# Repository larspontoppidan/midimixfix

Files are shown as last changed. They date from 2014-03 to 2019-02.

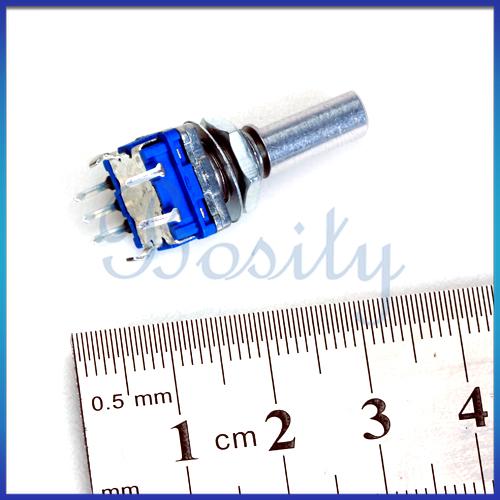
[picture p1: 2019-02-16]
HW/Components/Rotary encoder/14002056_5_image_81994.jpg

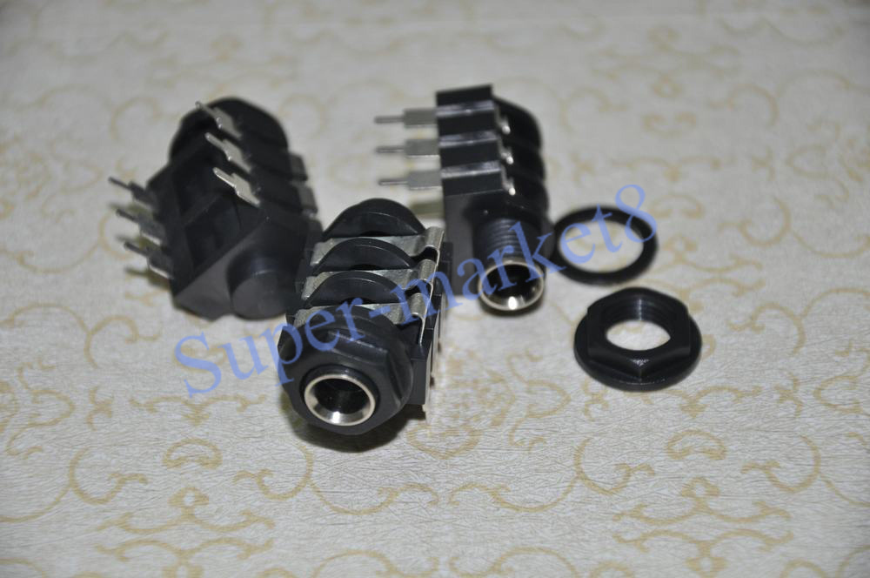
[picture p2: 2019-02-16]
HW/Components/JACK receptacle/B2.JPG

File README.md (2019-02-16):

# MidiMixFix

*Now open source!*

Midimixfix is a standalone MIDI processing unit with custom designed electronics and software for mixing and processing streams of MIDI.

## Features at a glance

- Two MIDI inputs and one MIDI output.
- Two pedal inputs assignable to MIDI controllers.
- All inputs can have their MIDI channels filtered, reassigned, merged or individually processed very flexibly. MIDI messages can be modified and generated.
- Midimixfix is independent of a PC. Configuration is done using the buttons and display.
- Transformation of continuous MIDI message values based on configurable curves.
- Splitting of polyphony into seperate monophonic MIDI channels for control of individual notes.
- Aftertouch processing, smoothing and reassignment to other controllers.
- Conditional processing based on triggers or keyboard split.
- Analysis of MIDI data with the MIDI logger feature.
- Save/Load of configuration presets. One preset is loaded at start up.
- Software in Midimixfix can be upgraded using the USB connection.



Back of midimixfix

## Links

Read more here: https://larsee.com/blog/tag/midimixfix.html

Youtube video demonstrations:
- [Midimixfix demonstration, fixing key velocity using curve filter](https://www.youtube.com/watch?v=JRt7MXFQuEk)
- [Vibrato Pedal on a Piano? Enhancing Rachmaninoff with Midimixfix](https://www.youtube.com/watch?v=KIDRwiXo5tw)
- [Polyphonic aftertouch effects with Midimixfix channel split feature](https://www.youtube.com/watch?v=yqUHe00-khM)

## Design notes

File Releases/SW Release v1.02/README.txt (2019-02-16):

Programming MidiMixFix in Windows:
-----------------------------------

Three things are needed to flash upgrade the software in MidiMixFix with the contents of this zip file:

1. USBasp driver installed

2. Avrdude installed (available in WinAVR package)

3. Midimixfix in bootloader mode connected with USB cable

Then, the batch file "Flash Midimixfix(...).bat" should run successfully. 

Detailed instructions:
----------------------

1. Installing USBasp driver:

- Go to http://www.fischl.de/usbasp/  and download for driver for windows, for example: http://www.fischl.de/usbasp/usbasp-windriver.2011-05-28.zip

- Unpack zip file.

- While holding select button, connect MidiMixFix to PC with USB cable, in order to activate the USBasp device. Now Windows will discover a new USB device and may fail to install a driver for it. It this happens, go to control panel and find the non-working USB device, in properties change the driver to the one from the zip file.

2. Installing WinAVR:

- Go to http://sourceforge.net/projects/winavr/files/ and download the latest version of WinAVR. Install it.

3. A sure way to bring Midimixfix in bootloader mode is to hold down the Select button while connecting the USB cable. This will make Midimixfix start up in bootloader mode. The LCD may show two black bars in this mode.

Now execute "Flash MidiMixFix(...).bat"!

By Lars Ole Pontoppidan, 2014-01-19

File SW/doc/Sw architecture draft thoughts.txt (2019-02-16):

 12345678901234567890
----------------------
-                    -
-                    -
-                    -
-                    -
----------------------

----------------------
-In Flt Flt Flt Flt O-
- 1                 1-
- 2                 2-
-                    -
----------------------

Functions

In1
In2

All to chan 1
OY1

VelocityTransform1
VelocityTransform2
VelocityTransform3
VelocityTransform4
Arpeggiate
Poly To Channels
 Aftertouch
AfterTouch To Volume
Att Vel To Volume
Rel Vel To Volume

Kindof a simpler approach:

Use cases:
- Poly fan out

----------------------
- Preset  : 1        -
- V.Curve : Neutral  -
- Pedal   : Eff OnOff-
- Patch   : 3,127,128-
- Eff.mod : Poly2Chan-
- Eff.ctl : Volume   -
- Save to preset 1   -
----------------------

Preset:  1..16

Filter:  AllPass, NoCrap, OnlyNotes, OnlyChn1, OnlyChn2

V.Curve: Neutral, HardStart, SoftStart, HardEnd, 

Pedal:   Eff OnOff
         Volume
         Pan
         MidiCtl ..
         
PatchChg: Off
          3,127,128
         
Eff.Mode: Off
          PolyChan     Poly aftertouch to channels
          EPolyChan    Emulated poly aftertouch to channels
          EPitchBnd    Emulated pitch bend

For PolyChan:
          
Eff.Ctl : Volume       Poly aftertouch controls volume
          Pan          Poly aftertouch controls pan
          MidiCtl ..   Poly aftert. controls midictrl something

For EPolyChan:
          
Eff.Ctl : Volume       Poly aftertouch controls volume
          Pan          Poly aftertouch controls pan
          MidiCtl ..   Poly aftert. controls midictrl something

----------------------
- V.Curve : Neutral  -
- Pedal   : Eff OnOff-
- Eff.mode: Poly2Chan-
- Eff.ctrl: Volume   -
----------------------

GPIO BUDGET
-----------

Function        IO   Special
MIDI IO         2    UART
Sec. MIDI IO    4    UART
Display data    8    Same port
Display ctl     3
Pedal 1/2       2    ADC
Indicator led   1    Evt. pwm
V-USP           3    1x Ex. int.
Rotary enc      2    2x Ex. int.
Push buttons    2    

Total          25

---------------

Architecture

hal module sets up midi IO uarts and sends interrupts for the uart activities

midimessage module parses incoming midi data:

hal:ISR
 ->  midimessage:Parser 
     -> midiio:MsgAllocate   (reserve mmsg)
     -> midiio:MsgHandOver   (indicate mmsg is complete)
        -> midilogger
        -> midiprocess
        -> start transmission   

What if the parser works like this

hal     midiparser           midiio
        w. statemachine      w. buffer
 
ISR ->  Parser         ->    msg_index = StartNewMsg(source, midi_status)
                             AddMsgData(msg_index, midi_data)
                             FinishMsg(msg_index, message_status)

So, the software architecture should be modular.

In general the modules can do the following:

1. Monitor messages
2. Filter messages 
3. Change messages
4. Generate new messages
5. Have configuration options, a presentation in the menu
6. Have an entire LCD screen mode (curve edit, midi logger)

Is it feasible and desireable to have a module interface that can accomplish all this?

The modules must be able to:

A. Hook new message ISR
B. Hook tick ISR
C. Hook main thread idle loop
D. Call message generation API

The A, B, C, D possibilities are rather straightforward and will enable modules to solve 1, 2, 3, 4.

What is not solved at this point is 5, 6. 

What is required for a presentation in the menu? How should the menu look like?

Boot screen:

----------------------
|** Midimixfix 0.1 **|
|>Preset: <no preset>|
| In1 setup: Through |   | In1 setup: Process | | In1 setup: Through |
|  Send realtime msg.|
| In2 setup: Process |
|  Stop realtime msg.|   |  Send realtime msg.|
| Show...            |   | Show > status view | quick help, input log, output log
| Pass filter: ON    |
|  In1 only Ch1      |
|  In2 only Notes    |
|  In2 only Ch2      |
|  In2 only Notes,AT.|
|  Manage...         |   |  Manage > Add      |   / Remove / Reset
| Stop filter: ON    |
|  Stop C.Variation  |
|  Stop ProgChg      |
|  Stop ATouch       |
|  Manage...         |   |  Manage... Add     |   / Remove / Reset
| Map channel: ON    |
|  Map In1 Ch3       |
|  To  Ch7           |
|  Map In2 Ch*       |
|  To  Ch6           |
|  Manage...         |   |  Manage... Add     |   / Remove / Reset
| Map controller: ON |
|  Map C.Modulation  |
|  To  C.Expression  |
| Pedal 1: ON        |
|  Calib. 000 127    |
|  To  C.Expression  |
| Pedal 2: ON        |
|  Calib. 000 127    |
|  To  Chan.A.Touch  |
| Curve: ON          |
|  On N.On vel.      |
|  0,32,64,96,127    |
|  On A.Touch        |
|  0,32,64,96,127    |
|  On C.Modulation   |
|  0,32,64,96,127    |  On select the curve window is displayed
|  Manage            |  |  Manage: Add / Remove |
----------------------

Okay, so what general structure is needed in the menu system:

A menu item can be:
 - Titlemenu   
 - SubMenu    (indented by one)
 
A menu entity contains:
 - One TitleMenu (may change text)  EntityItem 0
 - Zero or more SubMenu items       EntityItem 1, 2, 3...

Both TitleMenu and SubMenu can react to user input:
 - User select: Example: edit mode 0 -> 1 -> 2 -> 0
 - User turn: If edit mode is 0 menu will scroll on to next menu item
 - User turn: If edit mode > 0, menu will send turn events to EntityItem
   Now EntityItem may change it's representation and cursor position

Generally, Menu module will request MenuEntities for their representation
when necessary:

  uint8_t  SomeFilterGetSubMenus(void)
  void     SomeFilterGetMenuText(char *dest, uint8_t item)   
              // 0 is TitleMenu, 1, 2... SubMenus

When user does something to a menu item, Menu module will call:

  uint8_t SomeFilterMenuEvent(uint8_t item, uint8_t edit_mode, uint8_t user_event, int8_t knob_delta)

The user_event can be:  
  0:   Exit
  1:   Select
  2:   Knob turned (no push)
  3:   Knob turned (push)
 
The knob_delta is a signed 8-bit indicating how much the know was turned

The function must return:
  Value: 0     Edit mode not available
  Value: 1-18  Set cursor here
  Flag:  0x20  Update this line in menu
  Flag:  0x40  Update entire menu
  Flag:  0x80  I want to control the entire LCD
  
If 0x80 is returned, the menu module will stop doing anything to the display and just keep on sending the user events to the module. When the menu module receives an Exit event, it will be sent to the module, and then the menu will take over the display again.

------ Phew. That should solve the requirements 5, 6.

To summarize, modules that integrates in the Midimixfix platform must implement seven functions:

 void Initialize(void)
 
 void MessageIsrHook(mmsg_t *msg)
 void TickIsrHook(void)
 void MainLoopHook(void)
 
 uint8_t GetSubMenuCount(void)
 void    GetMenuText(char *dest, uint8_t item)
 uint8_t MenuEvent(uint8_t item, uint8_t edit_mode, uint8_t user_event, int8_t knob_delta)

... Now. How to implement this interface. It has to be handled by a ModuleFactory module.

------- What filters makes sense to have:

Both pass filters  / stop filters and mapping seems to solve
related tasks. Does it make sense to have indivitual pass / stop / map
filters? Or should they be combined into one multipurpose filter?

Two filters:

---- Block filter ----

Allows a number of rules with the following structure:

Input:   In1 In2 In*
Mode:    Only allow / Stop
Subject: Chan1 - Chan16, 
         Notes, Key AT, Ctl.chg, Prog.chg, Chan.AT. P.Wheel, System

"In* only Chan1    "
"In2 stop Chan3    "

"In1 only prog.chg."

---- Map filter: ----

Allows rerouting of channels and controllers.

The rules have the following structure:

Input:   In1 In2 In*
Map:     Chan1 - Chan16, P.Wheel, Chan.AT, Ctl:0 to Ctl:64
To:      Chan1 - Chan16, P.Wheel, Chan.AT, Ctl:0 to Ctl:64, or NULL

Map and Block (OFF)
"In1 Chan2"
  To block"
"In:1 Ctl:4"
  To Ctl:6"
"In:1 Chan:1"
  To Chan:2

---- Curve filter: ----
   
Allows shaping 7-bit values according to curve settings

The curve rules have the following structure:

Input:    In1 In2 In*
Param.:   Note-On All, Note-On White, Note-On Black, Note-Off
          Key AT, Chan AT, 
Shape:    Low point, Curve type, High point

Neutral:              0   1  127
To lift up minimum:   30  1  127
To advance minimum:   -30 1  127

To use a non-linear curve:  0   0.8  127  (resembling gamma 0.8)
To use a non-linear curve:  0   1.3  127
To use a non-linear curve:  0   S    127  (having a more steep center)
To use a non-linear curve:  0   N    127  (having a more flat center)

The available non-linear curves could be:

"0.5", "0.8", "1.3", "2  ", "S", "N"

The filter algorithm to be used live would be like:

1. Look up value in non-linear curve table, or use directly
2. Multiply gain  (fixed point)
3. Add offset
4. Bounded conversion to non-fixed point, 0..127

Nice values: 32 0.8 137
             25 0.8 134

--------------------

What about presets???

The system should have a number presets, numbered 1, 2, 3...

The user can save / load to preset from a menu:

Example:

"Preset 10 mod. (+)"

Clicking the menu exposes two options:

"Preset 13 mod. (+)" 
"  Store"   ->   "  Store preset 12"
"  Load"    ->   "  Load preset 2"

Should components actively tell the preset module about their config
or should the preset module poll them somehow? The answer is what is 
the least burdensome for the components.

Preset polling: Solution A

uint8_t comp_SerializeGetSize();
void comp_SerializeSave(uint8_t *dest);
void comp_SerializeLoad(uint8_t *dest);

----------------

Send msg.   (0)

-------------------

2013-09-05

Den nuværende arkitektur begynder at vise sine mangler. Det største problem er at med en længere række moduler, der også genererer midi messages, kommer behovet for at kunne forbinde filtermoduler osv på genererede messages. Et andet problem er at mængden af moduler bliver overvældende og når man kun har brug for få moduler, er det uoverskueligt at skulle se på hele listen.

Det ville være genialt at kunne forbinde moduler med hinanden i en kæde. Men hvornår skal input a/input b og eller genererede messages behandles?

----------------------
- - MIDIMIXFIX -     -
- Super delay    DUP -
-                    -
- Add filter         -
- Midilog...         -
-                    -
----------------------

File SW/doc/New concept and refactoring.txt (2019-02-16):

2013/09/09

Before refactoring:

Program:   23658 bytes (36.1% Full)
(.text + .data + .bootloader)

Data:       1366 bytes (33.3% Full)
(.data + .bss + .noinit)

So, the current state of midimixfix is not really scaleable. If individual filters should handle messages from other filters / and or channels, is not controllable and behaviour may not be as desired.

The solution is let the processing have a chain of stuff to happen:

- MIDIMIXFIX -
Midi In1          >1  
Midi In2          >2
Generate msg.     >3
  Ch     : 1
  Type   : Patch Chg
  Value  : 3
Gen. msg          >3
  Ch     : 1
  Type   : Patch Chg
  Value  : 3
Pedal1            >1
  Ch     : 1
  Gain   : 125
  Offs   : 144
  Invert : False

Remap            1>1
  Map    : Chan 1
  To     : Discard

MidiOut          A>
  Runn. status : Off

How to implement the dynamic menu?

The current implementation works as follows:

main.c 
Catches UI events and passes them to:

menu.c 
The UI events updates menu selection state. Based on interaction with menuentities,
the LCD updates are sent to

lcd.c
which further on calls

hal.c
to actually send data to the display.

Now we want a menu metaphor with more than one mode.

1. There can be the top menu where all plugin configuration is visible
2. Then you can access management interface where plugins can be loaded / removed / reordered, and presets can be saved / loaded.

- MIDIMIXFIX -
Midi In1          >1  
Midi In2          >2
Generate msg.     >3
  Ch     : 1
  Type   : Patch Chg
  Value  : 3
Gen. msg          >3
  Ch     : 1
  Type   : Patch Chg
  Value  : 3
Pedal1            >1
  Ch     : 1
  Gain   : 125
  Offs   : 144
  Invert : False
Remap            1>1
  Map    : Chan 1
  To     : Discard
MidiOut          A>
  Runn. status : Off

+--------------------+
| Midi In2         >2|
|>Generate msg.    >3|
|- Ch     : 1        |
|  Type   : Patch Chg|
+--------------------+

+--------------------+
| Midi In2         >2|
|>Generate msg.    >3|
|  Ch     : 1        |
|** ADD:Midi In2   **|
+--------------------+

+--------------------+
| Midi In2         >2|
|>Generate msg.    >3|
|  Ch     : 1        |
|** LOAD PRESET:1  **|
+--------------------+

+--------------------+
| Midi In2         >2|
|>Generate msg.    >3|
|  Ch     : 1        |
|** REMOVE:Confirm **|
+--------------------+

+--------------------+
| Midi In2         >2|
|>Generate msg.    >3|
|  Ch     : 1        |
|** ERRORS:        **|
+--------------------+

Okay, so we need a secondary menu as an overlay taking up the bottom row of the display:

main.c 
Still gets the overall user events. They are passed to:

ui.c 
Handles the state of the entire user interface. 
The module may ask filtermenu.c to draw menu entries relating to the filters
The module may ask altmenu.c to draw the bottom line
But the module itself performs the menu actions

----- 2013-10-12

Now there is a completely new filter concept implemented. It is possible to route stuff in streams and order filters as desired.

The old strategy for filters, namely the block and map filter, now doesn't make as much sense anymore. Previously it was desireable to pack as much funcitonality into a single filter as possible to reduce the length of the static menu. Now it is better to have a larger number of simple filters to select from:

Previous "Block and map" is capable of:

Picking a channel / controller and changing into another channel, changing the controller type or discarding.

some channel    -> some channel / discard
some controller -> some controller / discard

Proposed bisection of the "block and map" filter":

-  " Route MIDI Chan 4>X"
   "  Chan. : 1         "

-  " Modify MIDI Chan  5"
   "  Set chan. : 4     "

-  " Route MIDI msg. 3>4"
   "  Type : NoteOn/Off "  NoteOn/Off, PWheel, KeyAfterT. Ch.AfterT., Patch, CC:Volume, CC:0x33

-  " Modify MIDI msg.  4"
   "  From : CC:Volume  "  
   "  To   : Ch.AfterT. "

-  " Value transform   5"
   "  Affect: N.On Black"    NoteOn, N.On White, N.On Black, NoteOff, 
   "  Start : 0         "
   "  Shape : S-shape   "    Linear, Gamma 0.8, S-shape, N-shape
   "  End   : 127       "

-  " Route all       4>X"

-  " Pedal IN1 (127)  >4"
   "  Ctrl. : CC:Sustain "
   "  Mode  : Dig. Inv.  " "An. Inv."
   "  Offset: 0          "
   "  Gain  : 40         "

-  " Generate MIDI   3>4"
   "  Trig.: None       "
   "  Msg. : Patch Chg. "
   "  Value: 44         "

-  " Polyphonic Split  4"
   "  Use chan. : 2     "
   "   to chan. : 8     "
   "  Msg. : Patch Chg. "
   "  Value: 44         "

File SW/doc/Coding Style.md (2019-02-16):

Larsp's Favorite C Coding Style
===============================

Author:   Lars Ole Pontoppidan
Date:     2013-05-03
Version:  1.0

Introduction
------------

This document defines guidelines for formatting, naming and for good practices writing C source code. Following the guideline should result in a consistent, easily readable and maintainable code base with a reduced likelihood of bugs compared to not using a consistent coding style. The intended use is for small to medium scale microcontroller based projects.

The guideline is primarily intended to serve as tool for the programmer, assisting in making  good naming and design decisions quickly. It is not intented to be a very detailed and strict specification that requires a lot of effort to follow. 

To achieve this, the guideline is kept short and simple. If, however, requirements are in the way of achieving the most readable and highest quality code, it may be acceptable to deviate from specific requirements on a limited basis.

Language compliance
-------------------

Good code compiles cleanly using current and future versions of compilers and is as portable as possible. The language compliance rules try to achieve this by discouraging the use of obsolete and nonstandard constructs and by configuring the compiler to help checking the code for problems as much as possible.

1. The source code must compile with no warnings and no errors, even on the highest warning level of the compiler (options -Wall -Wextra -Wextra -pedantic for gcc). The -Werror option is recommended because modules  warnings often disappear on subsequent builds that doesn't recompile all code modules, which can lead to ignored warnings.

2. The source code may use ISO-C99 features when it benefits code quality. Rarely used C99 features must be avoided, in particular those not supported by the gcc compiler.

3. Specific compiler language features such as the "GNU-ISMs", must be avoided.

4. Ancient C language constructs such as digraphs, trigraphs and implicit function declarations must be avoided.

Indentation and curly brackets
------------------------------

The indentation and bracket style defined here focus on readability over code density, and is inspired by modern curly bracket languages such as C# and Java, more than by traditional C dogma. 

5. Tab characters must never be used. They are not necessary and only add potential problems.

6. Four spaces must be used for indentation.

7. Blocks are written with curly brackets on seperate lines and both on same indentation level as the preceeding control statement. 

8. Statements in blocks must be indented by the four spaces of indentation.

9. Always use blocks after control statements. Single statements without the curly brackets block must be avoided. 

10. Lines must not exceed 100 characters. Consider breaking lines that exceed 80 characters if it increases readability. Indent after the line break such that  statements are aligned and readability is maximized.

11. Apply white space to make the code easy to read and comprehend. Align variables, declarations. Make space between operators. Don't make space between every single line of code. Remember, no tabs.

See "Appendix B. Source file example" for an example.

Integer types
-------------

Writing software close to the hardware on resource limited microcontrollers requires tight control of the data types used.

11. Explicit bit-width integer types must be used instead of the built-in types in C language. For example, use "uint8_t" and "int16_t" from "stdint.h" instead of "unsigned char" and "int". 

    - Exception: The "char" type may be preferred for character data.

12. A custom "bool_t" type alias must be used for boolean variables, to clearly communicate the intension of the variable. An example definition suitable for 8-bit microcontrollers could be: "typedef uint8_t bool_t;"

13. Boolean truth assignments must use TRUE and FALSE defines with the value 1 and 0.

14. When testing boolean variables, respect the C convention of regarding all non-zero values as true. Never test on equality with TRUE. 

Code modules and files
----------------------

15. All code must be partitioned in code modules. A code module is a source file and a header file with the same name except for the ending, which must be ".c" and ".h". There are exceptions where it doesn't make sense to have 1:1 correspondance between source and header files.

16. Use all lower case for filenames. 

17. Encapsulation. Code modules must solve a single task or have a single purpose. They must publicly expose only a minimal and easy to understand interface. Functions and variables that are not required to be public must be private.

18. A header file defines publicly exposed declarations for the code module, typically public functions.

19. Only publicly exposed variables should use the "extern" keyword. Not functions.

20. All header files must have an include guard similar to: "#ifdef SOME_HEADER_H ... #endif". See Appendix A for a suggested syntax.

21. Generally avoid exposing variables as public. Prefer GetX and SetX functions instead. This is good practice because it allows the getters and setters to perform dataprocessing or syncronisation tasks before accessing the value.

22. A source file must be composed with the following sections:

    - A. File header
    - B. Header file includes
    - C. Defines. (Preprocessor defines, const variables, enums, typedefs)
    - D. Private variables
    - E. Prototypes for private functions
    - F. Implementation of private functions
    - G. Implementation of public functions

23. Never include ".c" files

24. Make a code module dependant on as few other header files as possible.

25. Private variables MUST be declared static. This is necessary to make the private variables private and to avoid name collisions between code modules.

26. Private functions MUST be declared static. This is necessary to make the private functions private and to avoid name collisions between code modules.

Casing and prefixes
-------------------

This casing and prefix style is intended be practical and easy to use, while conveying information about scope and type of declarations. The style attempts to be roughly compatible with C library declarations. 

Preprocessor macros:
27.   Module scope:    UPPER_CASE
28.   Public:          MODNAME_UPPER_CASE
   
Type definitions:
29.   Module scope:    lowerCamelCase_t
30.   Public:          modname_lowerCamelCase_t
   
Function definitions:
31.   Module scope:    lowerCamelCase
32.   Public:          modname_lowerCamelCase
      
Variables, arrays, struct instances:
33.   Function scope:  lower_case
34.   Module scope:    UpperCamelCase
35.   Struct members:  UpperCamelCase
36.   Public:          modname_UpperCamelCase

Declarations may be decorated with further suffixes, such as _ISR or _P etc.

See Appendixes for examples of the casing and prefix style.

HUSK: Function pointer bør bruge typedef
HUSK: Structs bør bruge typedef
HUSK: Static variable inden i funktioner er DUMT
HUSK: Extern er ikke nodvendig i h fil (default man ikke bruger static)
HUSK: Prefer single return statement
HUSK: Avoid magic constats

Selection of names
------------------

37. Function names must describe an action and include a verb.

38. Variable names must nouns.

39. Use plural form for array names.

    - Example: "static curveFilter_t CurveFilters[CURVE_FILTER_COUNT];
    - Example: "static uint8_t QueueElements[STATUS_BUFFER_SIZE];"

40. Avoid using abbreviated words except for very common abbreviations.

41. Names must not exceed 32 characters. Find a shorter name or consider common word abbreviations.

42. Avrgcc specific: Functions working with program memory locations must be suffixed with _P.

43. Good practice: Function names must end with a suffix according to the scope they are allowed to be called from:

    - Only main thread: _MAIN
    - Only ISR sources: _ISR
    - Both ISR and main thread calls: _SAFE 
    - Not applicable to define scope: no suffix

Comments
--------

44. Don't comment the obvious. Comment the intention of the code. If heaps of comments are required to explain some code, prefer to find a better implementation.

45. Use // for comments. Single and multi line comments using /* */ must be avoided.

46. Function comments: Simple and obvious functions doesn't need comments. Functions that are not obvious should be sufficiently described for new readers to understand purpose and usage. Use for example the function comment style demonstated in Appendix.

47. Public functions should be  in the header file must be commented only in the header file.

48. Private functions must be commented in the source file.

48. The header file must include a description on the purpose and how to use the code module.

49. The comment for functions must describe purpose, input values and return values. 

50. Use for example the commenting style used in Appendix A and B.

See Appendix A and B for a suggested white space style.

Various good coding practices
-----------------------------

53. All microcontroller specifics, such as SFR (special function register) accesses, ISR (interrupt service routinges) should be performed in a hal code module. The hal module should only perform a simple abstraction, or limited lowlevel processing.

54. Remember to use volatile for variables accessed by both ISR and main thread functions. Use necessary means to avoid race conditions, deadlocks etc.

55. Use const on function parameters if they are pointers, and the function doesn't touch the data that is pointed on.

56. Avoid using function scope static variables. It hides code module state for the reader. Use a file scope private variable instead.

57. When defining function pointers, first define the function pointer type with a typedef and a telling name. This will hugely increase readability.

58. Do bounds checking of array indexes when writing in arrays. If possible, verify integrity of pointers before writing to them.

59. Prefer inline functions over preprocessor macros.

APPENDIX A. Header file example
-------------------------------

APPENDIX B. Source file example
-------------------------------

//
// Filename    : codestyledemo.c
// Code module : Code style demonstration module
// Project     : Midimixfix
// URL         : http://larsee.dk
//
// --------------------------------  LICENSE  -----------------------------------
//
// Copyright (c) 2013, Lars Ole Pontoppidan (Larsp)
// All rights reserved.
//
// Redistribution and use in source and binary forms, with or without
// modification, are permitted provided that the following conditions are met:
// *  Redistributions of source code must retain the above copyright
//    notice, this list of conditions and the following disclaimer.
// *  Redistributions in binary form must reproduce the above copyright
//    notice, this list of conditions and the following disclaimer in the
//    documentation and/or other materials provided with the distribution.
// *  Neither the name of the original author (Lars Ole Pontoppidan) nor the
//    names of its contributors may be used to endorse or promote products
//    derived from this software without specific prior written permission.
//
// THIS SOFTWARE IS PROVIDED BY THE COPYRIGHT HOLDERS AND CONTRIBUTORS "AS IS" AND
// ANY EXPRESS OR IMPLIED WARRANTIES, INCLUDING, BUT NOT LIMITED TO, THE IMPLIED
// WARRANTIES OF MERCHANTABILITY AND FITNESS FOR A PARTICULAR PURPOSE ARE
// DISCLAIMED. IN NO EVENT SHALL THE COPYRIGHT OWNER OR CONTRIBUTORS BE LIABLE FOR
// ANY DIRECT, INDIRECT, INCIDENTAL, SPECIAL, EXEMPLARY, OR CONSEQUENTIAL DAMAGES
// (INCLUDING, BUT NOT LIMITED TO, PROCUREMENT OF SUBSTITUTE GOODS OR SERVICES;
// LOSS OF USE, DATA, OR PROFITS; OR BUSINESS INTERRUPTION) HOWEVER CAUSED AND
// ON ANY THEORY OF LIABILITY, WHETHER IN CONTRACT, STRICT LIABILITY, OR TORT
// (INCLUDING NEGLIGENCE OR OTHERWISE) ARISING IN ANY WAY OUT OF THE USE OF THIS
// SOFTWARE, EVEN IF ADVISED OF THE POSSIBILITY OF SUCH DAMAGE.
//
//
// ------------------------------  DESCRIPTION  ---------------------------------
//
// This code module is not really a code module that makes any sense, but it 
// demonstrates how to apply Larsp's Favorite C Coding Style (LFCCS).
//
// Implements:
// *  This
// *  That
// *  But not that
//

// -------------------------------  INCLUDES  -----------------------------------

#include "common.h"
#include "codestyledemo.h"
#include <string.h>

// --------------------------  TYPES AND CONSTANTS  -----------------------------

typedef struct
{
    uint8_t midiStatus;
    uint8_t midiParam[2];
} message_t;

#define MESSAGES_MAX 20

// Menu system defines
#define EDIT_MODE_ROOT    0
#define EDIT_MODE_CHANNEL 1

// ----------------------------  LOCAL VARIABLES  -------------------------------

static uint8_t   messageCount;
static message_t messages[MESSAGES_MAX];

static char titleString[] PROGMEM = "Generate msg. ";

// ------------------------------  PROTOTYPES  ----------------------------------

static void ResetMessage(uint8_t msg);
static void EditChannel(uint8_t msg, int8_t delta);

// ---------------------------  PRIVATE FUNCTIONS  ------------------------------

static void ResetMessage(uint8_t msg)
{
    // Default to program change on channel 1 patch 1
    Messages[msg].MidiStatus = MIDI_STATUS_PROG_CHANGE;
    Messages[msg].MidiParam[0] = 0;
}

static void EditChannel(uint8_t msg, int8_t delta)
{
    uint8_t chan;

    // Modify lower nibble of midi status with delta:

    chan = Messages[msg].MidiStatus & MIDI_CHANNEL_MASK;
    chan = util_boundedAddInt8(chan, 0, 15, delta);
    Messages[msg].MidiStatus = (Messages[msg].MidiStatus & (~MIDI_CHANNEL_MASK)) | chan;
}

// ---------------------------  PUBLIC FUNCTIONS  -------------------------------

void cstyle_initialize(void)
{
    uint8_t i;

    MessageCount = 0;

    for (i = 0; i < MESSAGES_MAX; i++)
    {
        ResetMessage(i);
    }
}

uint8_t genmsg_menuGetSubCount(void)
{
    return MessageCount;
}

void genmsg_menuGetText(char *dest, uint8_t item)
{
    if (item == 0)
    {
        util_strCpy_P(dest, TitleString);
        util_strWriteNumberParentheses(&(dest[14]), MessageCount);
    }
    else
    {
        // Write the decoded message. Move from message to mmsg_t
        mmsg_t msg;
        msg.flags = MMSG_FLAG_MSG_OK;
        msg.midi_status = Messages[item-1].MidiStatus;
        msg.midi_data[0] = Messages[item-1].MidiParam[0];
        msg.midi_data[1] = Messages[item-1].MidiParam[1];
        msg.midi_data[2] = Messages[item-1].MidiParam[2];
        msg.midi_data_len = mmsg_dataCountGet(msg.midi_status);

        mmsg_WriteMsgParsed(dest, &msg);
    }
}

// fooBar is intended to demonstrate coding style and not much else.
//
// Beware that the code may become sentient and take over your computer.
//
// Parameters:     
//    bar:                   This is where you buy beer
//    a_long_variable_name:  Not used
//    a_similar_variable:    Not used either
//    
// Return value:    The fooBar calculated
//   
uint8_t fooBar(uint8_t bar, uint32_t a_long_variable_name, 
                            uint32_t a_similar_variable)
{
    UNUSED(a_long_variable_name);
    UNUSED(another_long_similar_variable);

    uint16_t i = 0;
    uint8_t ret = 0;    

    // The following statement is genius    
    if (bar == SPECIAL_NUMBER)
    {
        uint8_t j;
        
        //  The following loop is pure nonsense  
        for (j = 2; j < 42; j++)
        {
            switch (i)
            {
            case 0:
                i = 4 + (2 * 2);
                break;
                
            case 1:
                // Do nothing because this of this or that
                break;
            
            default:
                if (checkOtherStuff(i * j))
                {
                    ret = j;
                }
            }
        }
    }
    else if (bar == ANOTHER_NUMBER)
    {
        ret = bar;
    }
    else
    {
        // Don't do anything because of this or that.
    }
    
    return ret;        
}

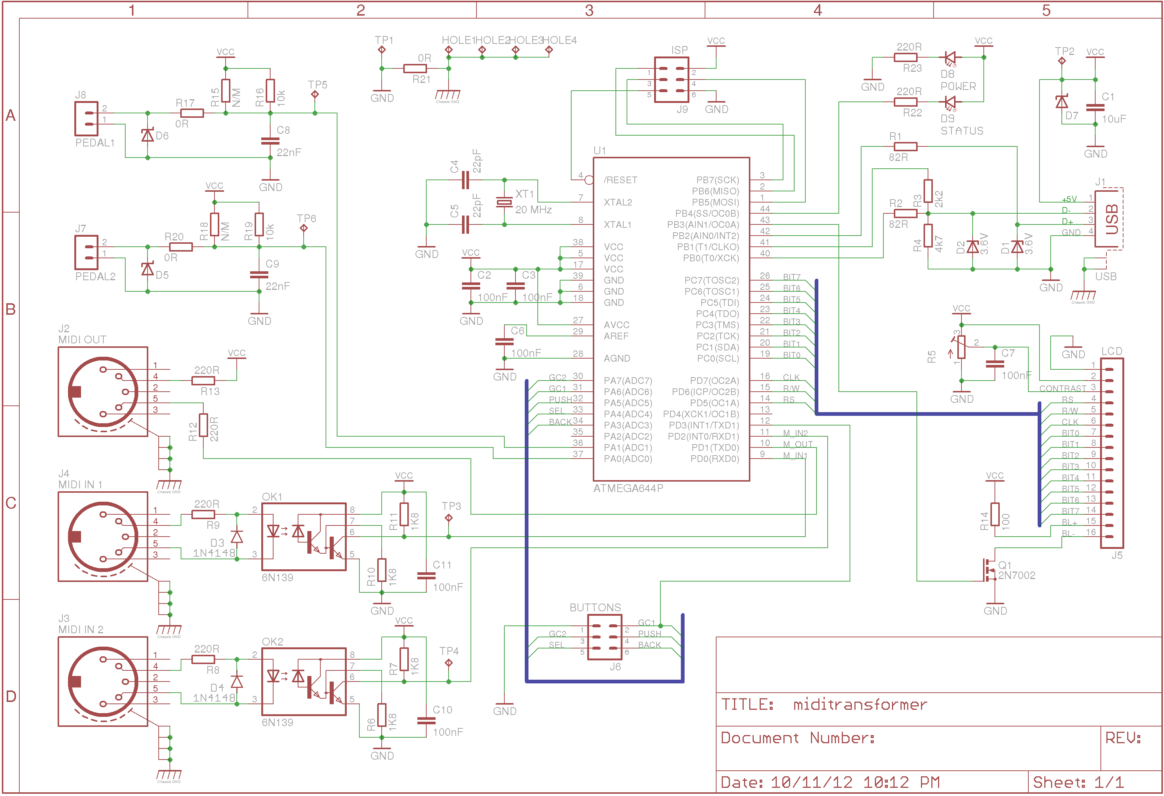
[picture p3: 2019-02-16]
Releases/HW Release Rev 1/midimixfix schematic.png

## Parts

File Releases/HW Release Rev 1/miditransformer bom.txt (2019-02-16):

Partlist

Exported from miditransformer.sch at 11/18/12 11:46 AM

EAGLE Version 5.11.0 Copyright (c) 1988-2010 CadSoft

Part     Value          Device            Package          Library    Sheet

C1       10uF           C-EU_1210R        C1210            cap        1
C2       100nF          C-EU_0805R        C0805            cap        1
C3       100nF          C-EU_0805R        C0805            cap        1
C4       22pF           C-EU_0805R        C0805            cap        1
C5       22pF           C-EU_0805R        C0805            cap        1
C6       100nF          C-EU_0805R        C0805            cap        1
C7       100nF          C-EU_0805R        C0805            cap        1
C8       22nF           C-EU_0805R        C0805            cap        1
C9       22nF           C-EU_0805R        C0805            cap        1
C10      100nF          C-EU_0805R        C0805            cap        1
C11      100nF          C-EU_0805R        C0805            cap        1
D1       3.6V           ZENER-DIODEDO34-7 DO34Z7           _newbylars 1
D2       3.6V           ZENER-DIODEDO34-7 DO34Z7           _newbylars 1
D3       1N4148         1N4148MINIMELF    MINIMELF         _newbylars 1
D4       1N4148         1N4148MINIMELF    MINIMELF         _newbylars 1
D5                      SUPPRESSOR-SMB    SMB              _newbylars 1
D6                      SUPPRESSOR-SMB    SMB              _newbylars 1
D7                      SUPPRESSOR-SMB    SMB              _newbylars 1
D8       POWER          LTL-1CHG          LED3MM           leds       1
D9       STATUS         LTL-1CHG          LED3MM           leds       1
HOLE1    HOLE_PAD       HOLE_PAD          HOLE_PAD_3.2     _newbylars 1
HOLE2    HOLE_PAD       HOLE_PAD          HOLE_PAD_3.2     _newbylars 1
HOLE3    HOLE_PAD       HOLE_PAD          HOLE_PAD_3.2     _newbylars 1
HOLE4    HOLE_PAD       HOLE_PAD          HOLE_PAD_3.2     _newbylars 1
J1       USB            PN61729-S         PN61729-S        _newbylars 1
J2       MIDI OUT       DIN5_FEMALE_PCB   DIN5_FEM_UNIV    _newbylars 1
J3       MIDI IN 2      DIN5_FEMALE_PCB   DIN5_FEM_UNIV    _newbylars 1
J4       MIDI IN 1      DIN5_FEMALE_PCB   DIN5_FEM_UNIV    _newbylars 1
J5       LCD            HEADER2X8LS       HDR_S_2X8        con-head   1
J6       BUTTONS        HEADER2X3S        HDR_S_2X3        con-head   1
J7       PEDAL2         HEADER1X2KK       MOLEX_KK_HDR2_FL con-head   1
J8       PEDAL1         HEADER1X2KK       MOLEX_KK_HDR2_FL con-head   1
J9       ISP            HEADER2X3         HDR_2X3          _newbylars 1
OK1      6N139          6N138DIL08        DIL08            _newbylars 1
OK2      6N139          6N138DIL08        DIL08            _newbylars 1
Q1       2N7002         2N7002            SOT23            fet        1
R1       82R            R-EU0805          R0805            _newbylars 1
R2       82R            R-EU0805          R0805            _newbylars 1
R3       2k2            R-EU0805          R0805            _newbylars 1
R4       4k7            R-EU0805          R0805            _newbylars 1
R5                      R-TRIMM           RTRIM3339P       _newbylars 1
R6       1K8            R-EU0805          R0805            _newbylars 1
R7       1K8            R-EU0805          R0805            _newbylars 1
R8       220R           R-EU0805          R0805            _newbylars 1
R9       220R           R-EU0805          R0805            _newbylars 1
R10      1K8            R-EU0805          R0805            _newbylars 1
R11      1K8            R-EU0805          R0805            _newbylars 1
R12      220R           R-EU0805          R0805            _newbylars 1
R13      220R           R-EU0805          R0805            _newbylars 1
R14      100            R-EULEADED-7.5    0207/7           _newbylars 1
R15      N/M            R-EU0805          R0805            _newbylars 1
R16      10k            R-EU0805          R0805            _newbylars 1
R17      0R             R-EU0805          R0805            _newbylars 1
R18      N/M            R-EU0805          R0805            _newbylars 1
R19      10k            R-EU0805          R0805            _newbylars 1
R20      0R             R-EU0805          R0805            _newbylars 1
R21      0R             R-EU0805          R0805            _newbylars 1
R22      220R           R-EU0805          R0805            _newbylars 1
R23      220R           R-EU0805          R0805            _newbylars 1
TP1      TPTH-15-06     TPTH-15-06        TP-TH-15-06      _newbylars 1
TP2      TPTH-15-06     TPTH-15-06        TP-TH-15-06      _newbylars 1
TP3      TPTH-15-06     TPTH-15-06        TP-TH-15-06      _newbylars 1
TP4      TPTH-15-06     TPTH-15-06        TP-TH-15-06      _newbylars 1
TP5      TPTH-15-06     TPTH-15-06        TP-TH-15-06      _newbylars 1
TP6      TPTH-15-06     TPTH-15-06        TP-TH-15-06      _newbylars 1
U1       ATMEGA644P     ATMEGA644P        TQFP44           avr-mcu    1
XT1      20 MHz         XTAL_HC49         HC49             crystal    1

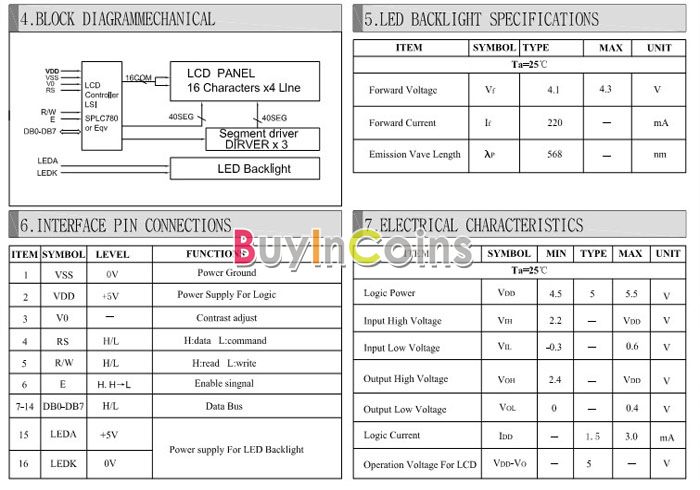
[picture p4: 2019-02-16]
HW/Components/LCD Module/2004-lcd-module_06.jpg

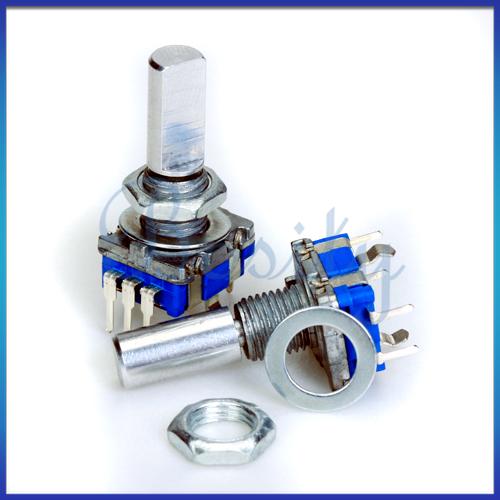
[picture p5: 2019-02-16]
HW/Components/Rotary encoder/14002056_3_image_92742.jpg

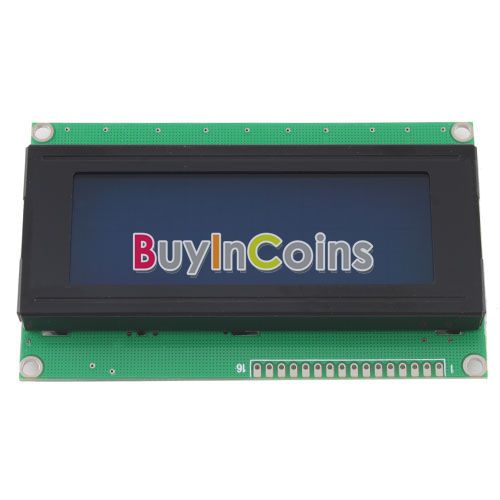
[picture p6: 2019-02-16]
HW/Components/LCD Module/2004-lcd-module_01.jpg

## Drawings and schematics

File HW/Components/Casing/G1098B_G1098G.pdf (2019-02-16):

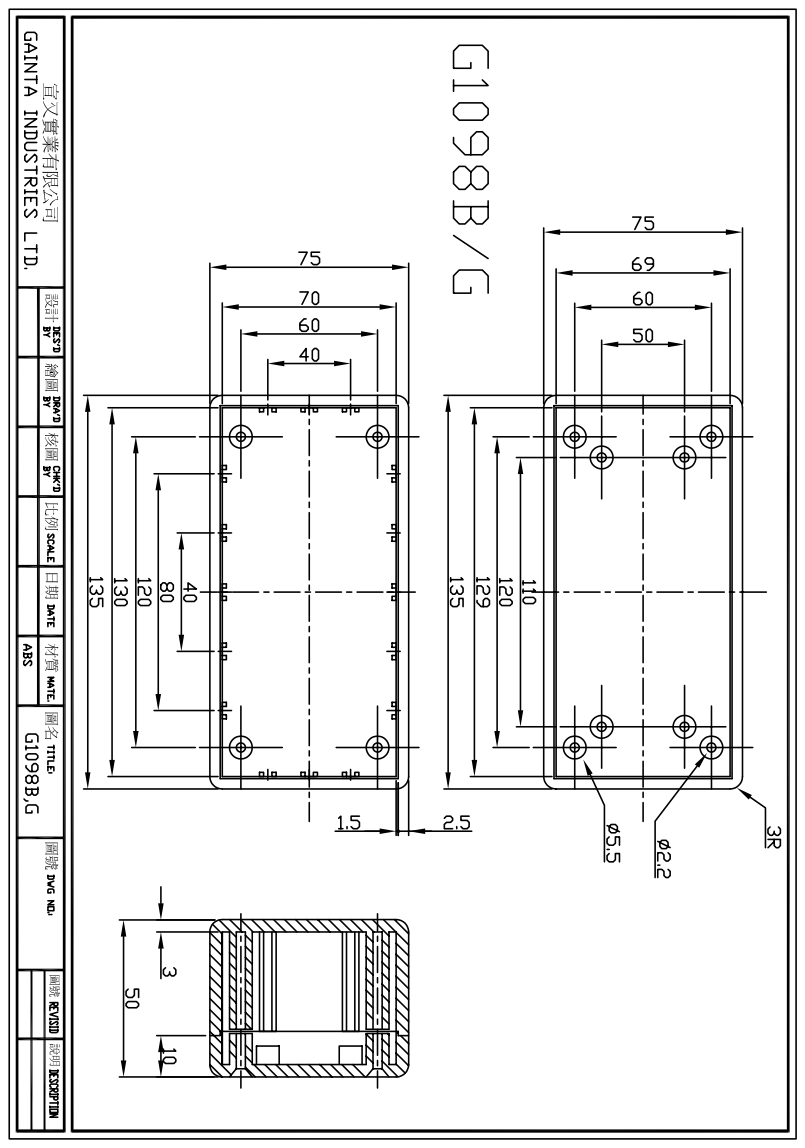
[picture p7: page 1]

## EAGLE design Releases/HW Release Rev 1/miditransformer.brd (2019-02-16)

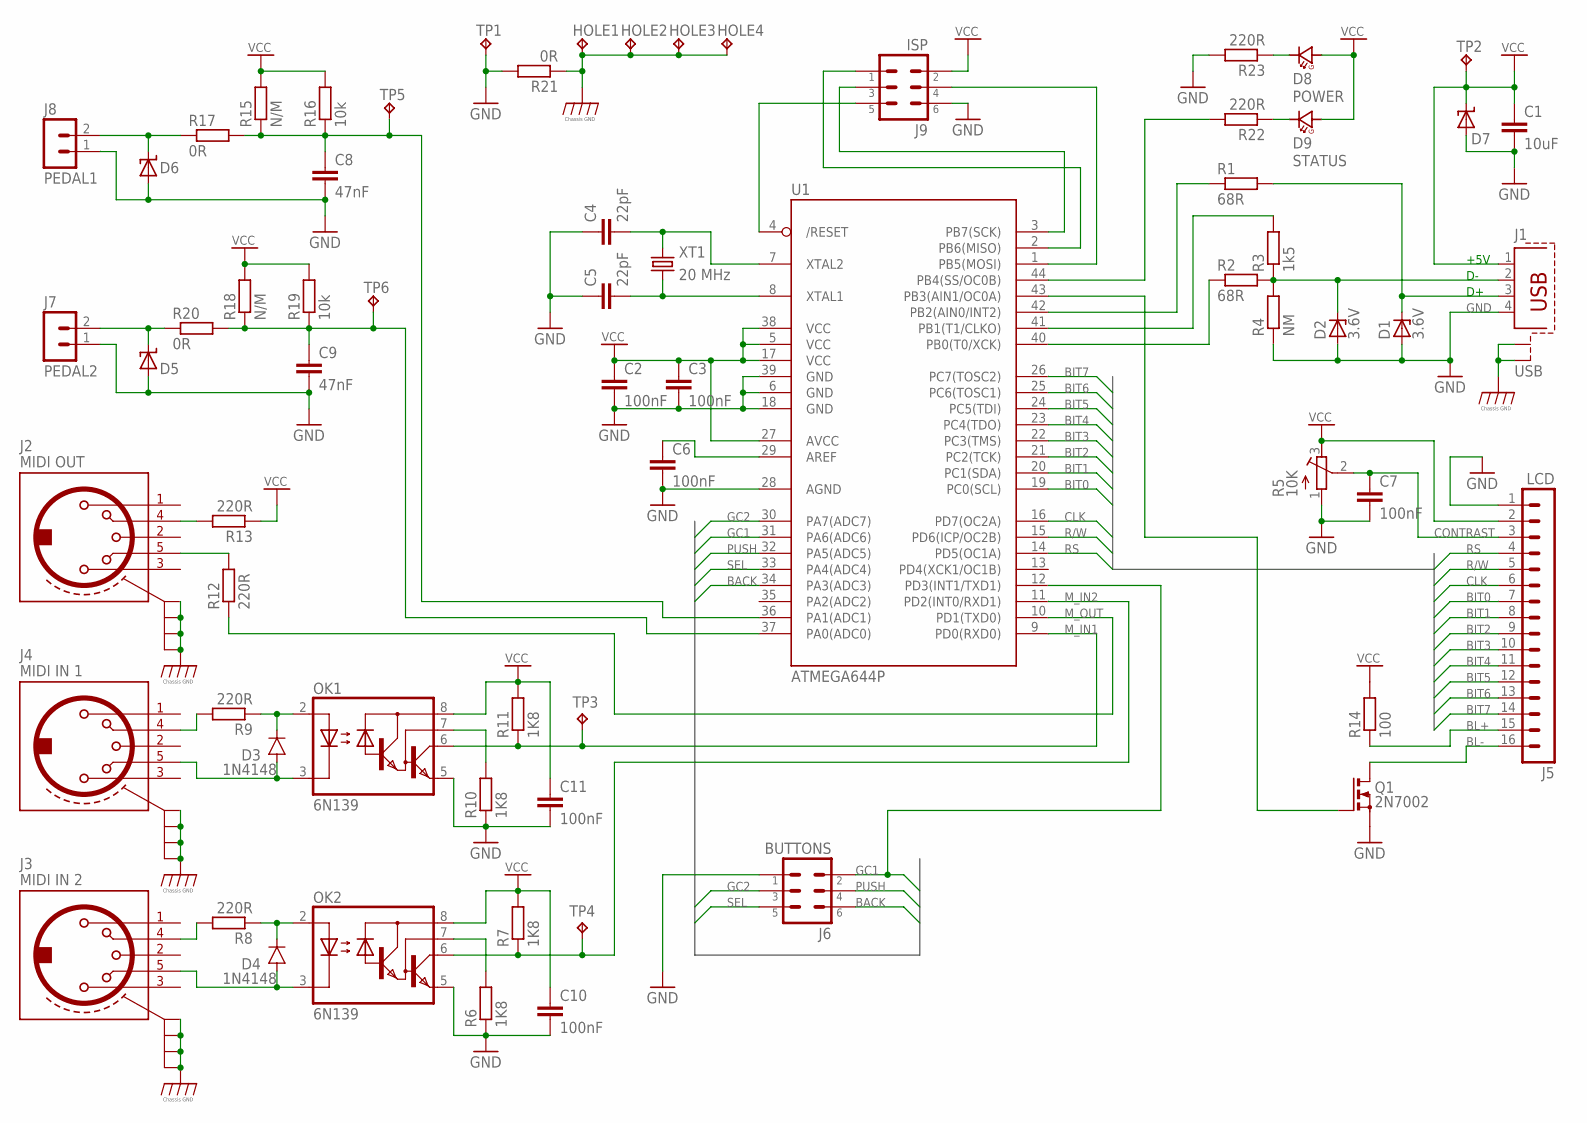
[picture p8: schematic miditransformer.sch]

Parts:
C1: 10uF; C1210
C2, C3, C6, C7, C10, C11: 100nF; C0805
C4, C5: 22pF; C0805
C8, C9: 47nF; C0805
D1, D2: 3.6V; DO34Z7
D3, D4: 1N4148; MINIMELF
D5, D6, D7: SUPPRESSOR-SMB; SMB
D8: POWER; LED3MM
D9: STATUS; LED3MM
HOLE1, HOLE2, HOLE3, HOLE4: HOLE_PAD; HOLE_PAD_3.2
J1: USB; PN61729-S
J2: MIDI OUT; DIN5_FEM_UNIV
J3: MIDI IN 2; DIN5_FEM_UNIV
J4: MIDI IN 1; DIN5_FEM_UNIV
J5: LCD; HDR_S_2X8
J6: BUTTONS; HDR_S_2X3
J7: PEDAL2; MOLEX_KK_HDR2_FL
J8: PEDAL1; MOLEX_KK_HDR2_FL
J9: ISP; HDR_2X3
OK1, OK2: 6N139; DIL08
Q1: 2N7002; SOT23
R1, R2: 68R; R0805
R3: 1k5; R0805
R4: NM; R0805
R5: 10K; RTRIM3339P
R6, R7, R10, R11: 1K8; R0805
R8, R9, R12, R13, R22, R23: 220R; R0805
R14: 100; 0207/7
R15, R18: N/M; R0805
R16, R19: 10k; R0805
R17, R20, R21: 0R; R0805
TP1, TP2, TP3, TP4, TP5, TP6: TPTH-15-06; TP-TH-15-06
U1: ATMEGA644P; TQFP44
XT1: 20 MHz; HC49

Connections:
BACK: J6.6, U1.34 (PA3(ADC3))
BIT0: J5.7, U1.19 (PC0(SCL))
BIT1: J5.8, U1.20 (PC1(SDA))
BIT2: J5.9, U1.21 (PC2(TCK))
BIT3: J5.10, U1.22 (PC3(TMS))
BIT4: J5.11, U1.23 (PC4(TDO))
BIT5: J5.12, U1.24 (PC5(TDI))
BIT6: J5.13, U1.25 (PC6(TOSC1))
BIT7: J5.14, U1.26 (PC7(TOSC2))
BL+: J5.15, R14.1
BL-: J5.16, Q1.3 (D)
CLK: J5.6, U1.16 (PD7(OC2A))
CONTRAST: C7.1, J5.3, R5.2 (S)
GC1: J6.2, U1.12 (PD3(INT1/TXD1)), U1.31 (PA6(ADC6))
GC2: J6.3, U1.30 (PA7(ADC7))
GND: C1.2, C2.2, C3.2, C4.1, C5.1, C6.2, C7.2, C8.2, C9.2, C10.2, C11.2, D1.A, D2.A, D5.A, D6.A, D7.A, J1.4, J5.1, J6.1, J7.1, J8.1, J9.6, OK1.5 (GND), OK2.5 (GND), Q1.2 (S), R4.1, R5.1 (E), R6.1, R10.1, R21.2, R23.2, TP1.1, U1.6 (GND), U1.18 (GND), U1.28 (AGND), U1.39 (GND)
M_IN1: OK1.6 (VO), R11.1, TP3.1, U1.9 (PD0(RXD0))
M_IN2: OK2.6 (VO), R7.1, TP4.1, U1.11 (PD2(INT0/RXD1))
M_OUT: R12.1, U1.10 (PD1(TXD0))
unnamed: D1.C, J1.3, R1.2
unnamed: D2.C, J1.2, R2.2, R3.1, R4.2
unnamed: R1.1, U1.42 (PB2(AIN0/INT2))
unnamed: R2.1, U1.40 (PB0(T0/XCK))
unnamed: C5.2, U1.8 (XTAL1), XT1.2
unnamed: R3.2, U1.41 (PB1(T1/CLKO))
unnamed: C4.2, U1.7 (XTAL2), XT1.1
unnamed: D9.C, R22.1
unnamed: OK2.7 (VB), R6.2
unnamed: J9.5, U1.4 (/RESET)
unnamed: J9.1, U1.2 (PB6(MISO))
unnamed: J9.3, U1.3 (PB7(SCK))
unnamed: J9.4, U1.1 (PB5(MOSI))
unnamed: D3.A, J4.5, OK1.3 (C)
unnamed: D4.C, OK2.2 (A), R8.1
unnamed: D8.C, R23.1
unnamed: J3.4, R8.2
unnamed: D4.A, J3.5, OK2.3 (C)
unnamed: OK1.7 (VB), R10.2
unnamed: R22.2, U1.44 (PB4(SS/OC0B))
unnamed: Q1.1 (G), U1.43 (PB3(AIN1/OC0A))
unnamed: D3.C, OK1.2 (A), R9.1
unnamed: D6.C, J8.2, R17.1
unnamed: J4.4, R9.2
unnamed: J2.4, R13.2
unnamed: J2.5, R12.2
unnamed: D5.C, J7.2, R20.1
unnamed: C6.1, U1.29 (AREF)
unnamed: C9.1, R18.1, R19.1, R20.2, TP6.1, U1.37 (PA0(ADC0))
unnamed: C8.1, R15.1, R16.1, R17.2, TP5.1, U1.36 (PA1(ADC1))
P$1: HOLE1.P$0, HOLE2.P$0, HOLE3.P$0, HOLE4.P$0, J1.S1, J1.S2, J2.PE@1 (PE), J2.PE@2 (PE), J2.PE@3 (PE), J2.PE@4 (PE), J3.PE@1 (PE), J3.PE@2 (PE), J3.PE@3 (PE), J3.PE@4 (PE), J4.PE@1 (PE), J4.PE@2 (PE), J4.PE@3 (PE), J4.PE@4 (PE), R21.1
PUSH: J6.4, U1.32 (PA5(ADC5))
R/W: J5.5, U1.15 (PD6(ICP/OC2B))
RS: J5.4, U1.14 (PD5(OC1A))
SEL: J6.5, U1.33 (PA4(ADC4))
VCC: C1.1, C2.1, C3.1, C10.1, C11.1, D7.C, D8.A, D9.A, J1.1, J5.2, J9.2, OK1.8 (VCC), OK2.8 (VCC), R5.3 (A), R7.2, R11.2, R13.1, R14.2, R15.2, R16.2, R18.2, R19.2, TP2.1, U1.5 (VCC), U1.17 (VCC), U1.27 (AVCC), U1.38 (VCC)

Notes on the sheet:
+5V

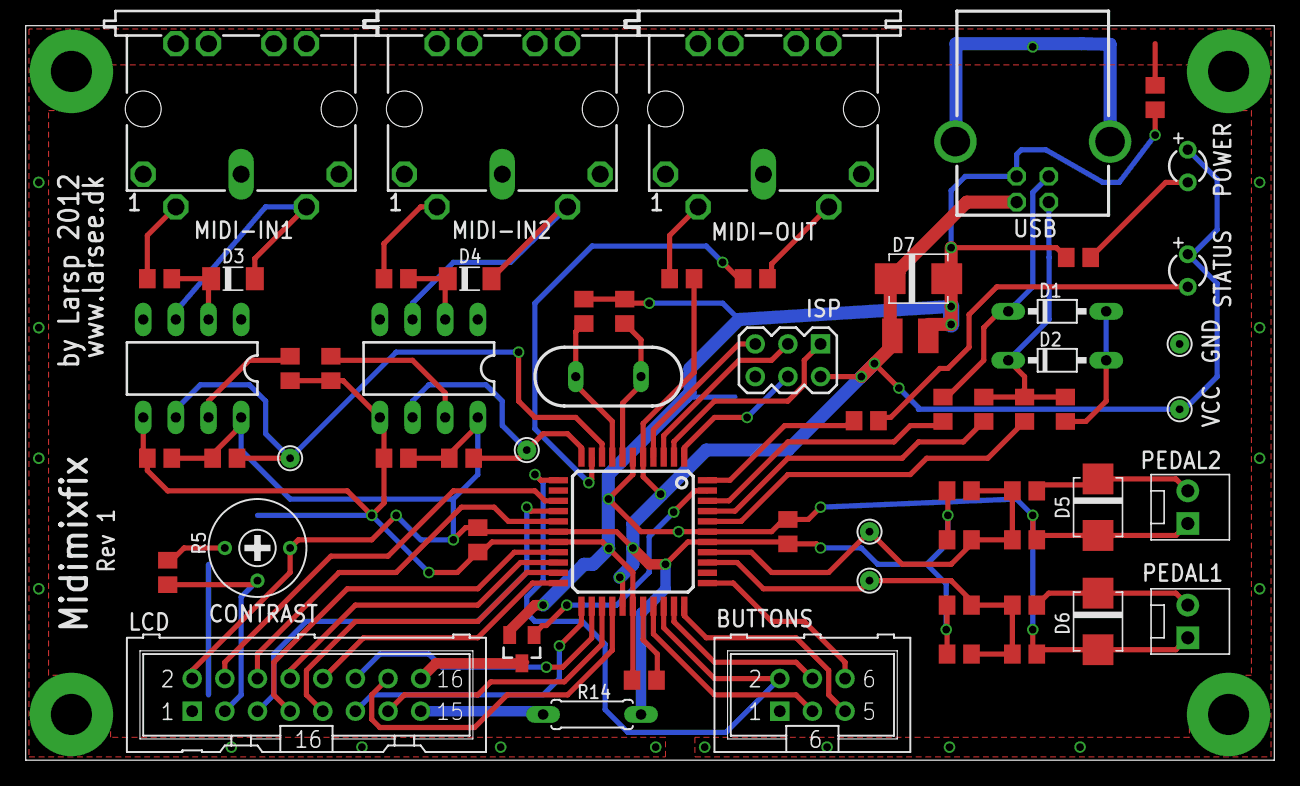
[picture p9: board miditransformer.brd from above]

Board: 2 copper layers, 97.2 x 57.1 mm, 67 parts (0 on the bottom side), 55 nets.

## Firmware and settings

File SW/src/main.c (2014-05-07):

//
// Filename    : main.c
// Code module : Entrypoint and top level functionality
// Project     : Midimixfix
// URL         : http://larsee.dk
//
// --------------------------------  LICENSE  -----------------------------------
//
// Copyright (c) 2013, Lars Ole Pontoppidan (Larsp)
// All rights reserved.
//
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
// THIS SOFTWARE IS PROVIDED BY THE COPYRIGHT HOLDERS AND CONTRIBUTORS "AS IS" AND
// ANY EXPRESS OR IMPLIED WARRANTIES, INCLUDING, BUT NOT LIMITED TO, THE IMPLIED
// WARRANTIES OF MERCHANTABILITY AND FITNESS FOR A PARTICULAR PURPOSE ARE
// DISCLAIMED. IN NO EVENT SHALL THE COPYRIGHT OWNER OR CONTRIBUTORS BE LIABLE FOR
// ANY DIRECT, INDIRECT, INCIDENTAL, SPECIAL, EXEMPLARY, OR CONSEQUENTIAL DAMAGES
// (INCLUDING, BUT NOT LIMITED TO, PROCUREMENT OF SUBSTITUTE GOODS OR SERVICES;
// LOSS OF USE, DATA, OR PROFITS; OR BUSINESS INTERRUPTION) HOWEVER CAUSED AND
// ON ANY THEORY OF LIABILITY, WHETHER IN CONTRACT, STRICT LIABILITY, OR TORT
// (INCLUDING NEGLIGENCE OR OTHERWISE) ARISING IN ANY WAY OUT OF THE USE OF THIS
// SOFTWARE, EVEN IF ADVISED OF THE POSSIBILITY OF SUCH DAMAGE.
//
//
// ------------------------------  DESCRIPTION  ---------------------------------
//
// This source is compiled for Atmega644p with 64KB flash, 4KB ram, 2KB EEPROM


// -------------------------------  INCLUDES  -----------------------------------

#include "common.h"

#include <util/delay.h>
#include <avr/pgmspace.h>

#include "hardwaretest/hardwaretest.h"
#include "hal.h"
#include "lcd.h"
#include "quaddecode.h"
#include "presetstorage.h"
#include "ui.h"
#include "errors.h"
#include "filterhooks.h"
#include "midiprocessing.h"
#include "midilog.h"
#include "menus/msgscreen.h"

// --------------------------  TYPES AND CONSTANTS  -----------------------------


// ----------------------------  LOCAL VARIABLES  -------------------------------


static bool_t UiSelectPushed = FALSE;
static bool_t UiBackPushed = FALSE;

// ------------------------------  PROTOTYPES  ----------------------------------

static void handleUi(void);

static void loadOrInitEeprom(void);

// ---------------------------  PRIVATE FUNCTIONS  ------------------------------


static void handleUi(void)
{
    int8_t i;

    i = quaddecode_getDelta_MAIN();

    while (i > 0)
    {
        ui_handleUserEvent(UI_EVENT_MOVE_UP);
        i--;
    }

    while (i < 0)
    {
        ui_handleUserEvent(UI_EVENT_MOVE_DOWN);
        i++;
    }

    i = quaddecode_getPushedDelta_MAIN();

    while (i > 0)
    {
        ui_handleUserEvent(UI_EVENT_MOVE_UP | UI_MOVE_FAST_MASK);
        i--;
    }

    while (i < 0)
    {
        ui_handleUserEvent(UI_EVENT_MOVE_DOWN | UI_MOVE_FAST_MASK);
        i++;
    }

    if (hal_buttonStatesGet() & HAL_BUTTON_SEL)
    {
        if (!UiSelectPushed)
        {
            ui_handleUserEvent(UI_EVENT_SELECT);
            UiSelectPushed = TRUE;
        }
    }
    else
    {
        UiSelectPushed = FALSE;
    }

    if (hal_buttonStatesGet() & HAL_BUTTON_BACK)
    {
        if (!UiBackPushed)
        {
            ui_handleUserEvent(UI_EVENT_BACK);
            UiBackPushed = TRUE;
        }
    }
    else
    {
        UiBackPushed = FALSE;
    }

    // TODO could use some better debounce filtering than just delaying here...
    _delay_ms(10);
}

static void loadOrInitEeprom(void)
{
    // Is eeprom contents acceptable?
    if (presets_validateEeprom())
    {
        uint8_t r;

        // Try to load preset 1 (no need to test first here)
        r = presets_load(0, FALSE);

        switch (r)
        {
        case PRESET_OK:
            // It worked!
            break;

        case PRESET_EMPTY:
            // Nothing there, load defaults
            midiproc_loadDefaultFilters();
            break;
        case PRESET_CHKSUM_ERROR:
            // This is critical, we must give up
            msgscreen_Show_P(PSTR("PRESET CORRUPT!"), 2);
            midiproc_loadDefaultFilters();
            break;
        default:
            // There was some other error, notify user
            msgscreen_Show_FormatP(PSTR("PRESET LOAD ERR:%i"), r, 1);
            midiproc_loadDefaultFilters();
            break;
        }
    }
    else
    {
        // Eeprom is invalid, uninitialized or in wrong format, notify user that
        // we had to reset it
        presets_resetEeprom();
        msgscreen_Show_P(PSTR("PRESETS RESET"), 3);

        // And load defaults
        midiproc_loadDefaultFilters();
    }
}


// ---------------------------  PUBLIC FUNCTIONS  -------------------------------

int main(void)
{
    // Hardware test mode?
    hwtest_enterIfTestMode();

    // Initialize basic modules
    err_initialize();
    hal_initialize();
    lcd_initialize();
    quaddecode_initialize();
    midiproc_initialize();
    midilog_initialize();

    // Initialize components
    FILTER_HOOKS_INITIALIZE();

    // Interrupts can start firing now
    hal_interruptsEnable();

    // Let menu start up
    ui_initialize();

    // Turn on display
    hal_lcdBacklightSet(TRUE);

    loadOrInitEeprom();

    midiproc_start_MAIN();

    while(TRUE)
    {
        // Component hooks for main loop
        FILTER_HOOKS_MAIN_LOOP();

        // Check if user did something on the controls
        handleUi();

        midilog_handleMainLoop();
        ui_handleMainLoopHandler();
    }

    return 0;
}

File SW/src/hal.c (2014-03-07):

/*
 * hal.c
 *
 *  Created on: Dec 8, 2012
 *      Author: lars
 */



#include "hal.h"
#include "errors.h"
#include "filterhooks.h"
#include <avr/io.h>
#include <avr/interrupt.h>
#include <util/delay.h>
#include <avr/wdt.h>
#include "quaddecode.h"
#include "midiprocessing.h"

/////////////////////////    Defines     /////////////////////////

#define QUADA_PIN   PIND
#define QUADA_PORT  PORTD
#define QUADA_DDR   DDRD
#define QUADA_MASK  (1u << 3)

#define QUADB_PIN   PINA
#define QUADB_PORT  PORTA
#define QUADB_DDR   DDRA
#define QUADB_MASK  (1u << 7)


#define BUTTONS_PIN   PINA
#define BUTTONS_PORT  PORTA
#define BUTTONS_DDR   DDRA

#define MIDI_BAUD_RATE 31250

// Debug signal is intended for timing measurements.
// It is pin 4 in J9 (ISP connector) and is driven high / low.
#define DEBUG_SIG_MASK (1u << 5)
#define DEBUG_SIG_PORT PORTB
#define DEBUG_SIG_DDR  DDRB


#define TX_BUFFER_MAX  30


// USB Hardware

#define USB_PORT         PORTB
#define USB_DDR          DDRB

#define USB_PULLUP_MASK  (1u << 1)
#define USB_DPLUS_MASK   (1u << 2)
#define USB_DMINUS_MASK  (1u << 0)


/////////////////////////   Variables    /////////////////////////

static uint16_t TickCount;

static uint8_t AdcState = 0;
static uint16_t AdcValue0;
static uint16_t AdcValue1;

static uint16_t AdcTemp;

// Midi transmit buffer
static uint8_t TxBuffer[TX_BUFFER_MAX];
static uint8_t TxBufferHead;
static uint8_t TxBufferTail;

/////////////////////////   Prototypes   /////////////////////////


static void midiIoSetup(void);
static void tickIsrSetup(void);
static void fastTimerSetup(void);
static void adcSetup(void);

static void outputTxComplete_ISR();

///////////////////////// Implementation /////////////////////////

void hal_initialize(void)
{
    wdt_disable();

    // Set unconfigured defaults on all IO to pull-up enabled inputs, except for
    // USB control signals, which should be high impedance to disable USB.
    PORTA = 0xFF;
    DDRA = 0;
    PORTB = ~(0x07);
    DDRB = 0;
    PORTC = 0xFF;
    DDRC = 0;
    PORTD = 0xFF;
    DDRD = 0;

    // Status led
    PORTB |= (1u << 4);
    DDRB |= (1u << 4);

    // LCD backlight
    PORTB &= ~(1u << 3);
    DDRB |= (1u << 3);

    // Debug signal is active low output:
    DEBUG_SIG_PORT &= ~DEBUG_SIG_MASK;
    DEBUG_SIG_DDR |= DEBUG_SIG_MASK;

    // Quadrature encoder, configure pull up enabled inputs
    QUADA_PORT |= QUADA_MASK;
    QUADA_DDR &= ~QUADA_MASK;

    QUADB_PORT |= QUADB_MASK;
    QUADB_DDR &= ~QUADB_MASK;

    // Setup quadrature signal change interrupts
    EICRA |= (1u << ISC10);  // INT1 (PD3) is on QUAD A signal
    EIMSK |= (1u << INT1);   // INT1 (PD3) is on QUAD A signal

    PCMSK0 |= (1u << PCINT7); // PCIN7 (PA7) is on QUAD B signal
    PCICR |= (1u << PCIE0);   // PCIN7 (PA7) is on QUAD B signal

    // Buttons, configure pull up enabled inputs
    BUTTONS_PORT |= (HAL_BUTTON_PUSH | HAL_BUTTON_SEL | HAL_BUTTON_BACK);
    BUTTONS_DDR &= ~(HAL_BUTTON_PUSH | HAL_BUTTON_SEL | HAL_BUTTON_BACK);

    // Init other stuff
    midiIoSetup();
    tickIsrSetup();
    fastTimerSetup();
    adcSetup();
}


void hal_statusLedSet(bool_t on)
{
    if (on)
    {
        PORTB &= ~(1u << 4);
    }
    else
    {
        PORTB |= (1u << 4);
    }

}

void hal_debugSignalSet(bool_t value)
{
    if (value)
    {
        DEBUG_SIG_PORT |= DEBUG_SIG_MASK;
    }
    else
    {
        DEBUG_SIG_PORT &= ~DEBUG_SIG_MASK;
    }

}


void hal_lcdBacklightSet(bool_t on)
{
    if (on)
    {
        PORTB |= (1u << 3);
    }
    else
    {
        PORTB &= ~(1u << 3);
    }

}


uint8_t hal_encoderQuadGet(void)
{
    uint8_t ret;

    ret = (QUADA_PIN & QUADA_MASK) ? HAL_ENCODER_QUAD_A : 0;
    ret |= (QUADB_PIN & QUADB_MASK) ? HAL_ENCODER_QUAD_B : 0;

    return ret;
}


ISR(INT1_vect)
{
    quaddecode_handleAChange_ISR(QUADB_PIN & QUADB_MASK, (BUTTONS_PIN & HAL_BUTTON_PUSH) == 0u);
}


ISR(PCINT0_vect)
{
    quaddecode_handleBChange_ISR(QUADA_PIN & QUADA_MASK, (BUTTONS_PIN & HAL_BUTTON_PUSH) == 0u);
}



uint8_t hal_buttonStatesGet(void)
{
    uint8_t ret;

    ret = BUTTONS_PIN & (HAL_BUTTON_PUSH | HAL_BUTTON_SEL | HAL_BUTTON_BACK);
    ret ^= (HAL_BUTTON_PUSH | HAL_BUTTON_SEL | HAL_BUTTON_BACK);

    return ret;
}

void hal_interruptsDisable(void)
{
    cli();
}

void hal_interruptsEnable(void)
{
    sei();
}


// MIDI Input1 / Input2 / Output UARTs


static void midiIoSetup(void)
{
    // Setup USART0. This is used for Input1 and Output
    ///////

    // Set baud rate (non-double speed mode)
    UBRR0 = 39; // F_CPU / (16 * MIDI_BAUD_RATE) - 1;

    // No double speed mode
    UCSR0A = 0u;

    // Enable receiver and transmitter
    UCSR0B = (1u << RXCIE0) | (1u << RXEN0) | (1u << TXEN0);

    // Set frame format: 8 data, 1 stop bit
    UCSR0C = (1u << UCSZ01) | (1u << UCSZ00);

    // Reset TX buffer
    TxBufferHead = 0;
    TxBufferTail = 0;

    // Setup USART1 for Input2 (only)
    ////////

    // Set baud rate (non-double speed mode)
    UBRR1 = 39; // F_CPU / (16 * MIDI_BAUD_RATE) - 1;

    // No double speed mode
    UCSR1A = 0u;

    // Enable receiver
    UCSR1B = (1u << RXCIE1) | (1u << RXEN1);

    // Set frame format: 8 data, 1 stop bit
    UCSR1C = (1u << UCSZ11) | (1u << UCSZ10);
}

ISR(USART0_RX_vect)
{
    uint8_t x;

    hal_statusLedSet(TRUE);
    x = UDR0;
    midiin_handleInput1_ISR(x);
    hal_statusLedSet(FALSE);
}

ISR(USART1_RX_vect)
{
    uint8_t x;

    hal_statusLedSet(TRUE);
    x = UDR1;
    midiin_handleInput2_ISR(x);
    hal_statusLedSet(FALSE);
}


// Midi out transmission on UART0, data register empty interrupt
ISR(USART0_UDRE_vect)
{
    hal_statusLedSet(TRUE);
    outputTxComplete_ISR();
    hal_statusLedSet(FALSE);
}

static void outputTxComplete_ISR()
{
    if ((UCSR0A & (1u << UDRE0)) != 0u)
    {
        // We are done transmitting, more bytes to send?

        if (TxBufferTail != TxBufferHead)
        {
            // Yes, send next byte
            UDR0 = TxBuffer[TxBufferTail];

            if (TxBufferTail >= (TX_BUFFER_MAX - 1))
            {
                TxBufferTail = 0;
            }
            else
            {
                TxBufferTail++;
            }
        }
        else
        {
            // We didn't find anything to send, or are already finished
            // Turn off this interrupt
            UCSR0B &= ~(1u << UDRIE0);
        }
    }
}


bool_t hal_getMidiTxBufferEmpty_ISR(void)
{
    return (TxBufferHead == TxBufferTail);
}
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

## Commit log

2012-08-09 Configured for ATmega32 on TP-USB-KEYB. Doesn't work!
    [bootloaderconfig.h, main.c]
2013-01-12 First commit. Basic functionality including midilogger and block filter works without problems
    [errors.c, hal.c, lcd.c]
2013-01-12 Curve filter implemented. Works great! Plus other minor adjustments.
2013-01-19 New generate msg filter implemented! OBS Currently refactoring into new coding style...
2013-01-19 Blockfilter and curvefilter simplified to not have Manage... Add/Remove but filtercount in ()
2013-02-24 100 Hz tick implemented and tested, works
2013-03-16 Menu added to superdelay and further fixes on superdelay. Works pretty well. Format print function implemented
    [main.c]
2013-03-16 Block filter completely rewritten. Now supports block and mapping in all sorts of ways. Works. Need a little refactoring and renaming
2013-05-19 Attempt at fixing chip erase. Doesn't seem to work though. Makefile fixed so fuses can be set on new AVRs by slowing down ISP
    [bootloaderconfig.h, main.c]
2013-05-19 Bootloader works with HAVE_CHIP_ERASE to 0. It doesn't appear to work. Bootloader condition now active.
    [bootloaderconfig.h]
2013-05-20 Bootloadercondition now with glitch filter.
    [main.c]
2013-07-07 Jul 7 2013 release. Compiles with avr-gcc 4.7.2, a number of bugs fixed
    [hal.c]
2013-10-07 Filter add remove reorder appearently works!
2013-10-07 Add remove reorder works 100% now. filtermenu implemented, seems to work
2013-10-13 Menu interface changed to not use get function for the menuInterface_t struct. The same principle will be applied to filters as it is more efficient.
2013-10-17 New function pointer based filter architecture implemented
2013-10-18 Route channel filter implemented. Various bugfixes.
    [midiprocessing.c]
2013-10-20 UI Menu implementation changed to use update requests instead of convoluted calling of ui_menuDrawItem. Current program:19284 ram:784
2013-10-20 Live update of menu items now possible in filters and used by Pedals
2013-10-20 filtermenu bugfix
2013-11-03 Preset saving/loading improved. Filter UIDs defined better.
2013-12-31 Improved quadrature decoder with noise rejection
    [hal.c, quaddecode.c]
2014-03-07 Route msg filter implemented
2014-03-07 New unified route / duplicate filter implemented. Works!
2014-03-07 V1.1 Release. Generate msg filter big improvement. Bug fix, midiproc_handleTick wasn't called!
    [hal.c, midigenerics.h, midiprocessing.c]
2014-05-04 Serious bug fixes! Duplicate filter numbering error. Similar named Instance[] vars were not static!
2014-05-06 AT Smooth filter implemented
2014-05-07 Resetter implemented. Preset save too big error handler.
    [main.c]
2014-05-16 Control noteon filter implemented
2014-05-16 Key split route filter implemented
2019-02-16 Convert NoteOn vel. 0 to NoteOff function moved to earlier on processing chain
2019-02-16 Releases folder added with all SW and HW releases
    [miditransformer.brd, miditransformer.sch]
2019-02-16 HW folder added and hardware rev. 1 pictures
    [miditransformer.brd, miditransformer.sch]
